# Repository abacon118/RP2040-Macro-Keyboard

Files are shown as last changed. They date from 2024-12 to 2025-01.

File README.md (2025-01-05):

# RP2040-Macro-Keyboard
This is designed to type commonly used text at the press of a button.  For example, if you type "thank you" 20 times a day, you could make that a button.  Working in IT, I can type the same server names or IP addresses multiple times in a span of a few minutes.  This allows me to type those server names at the press of one button.

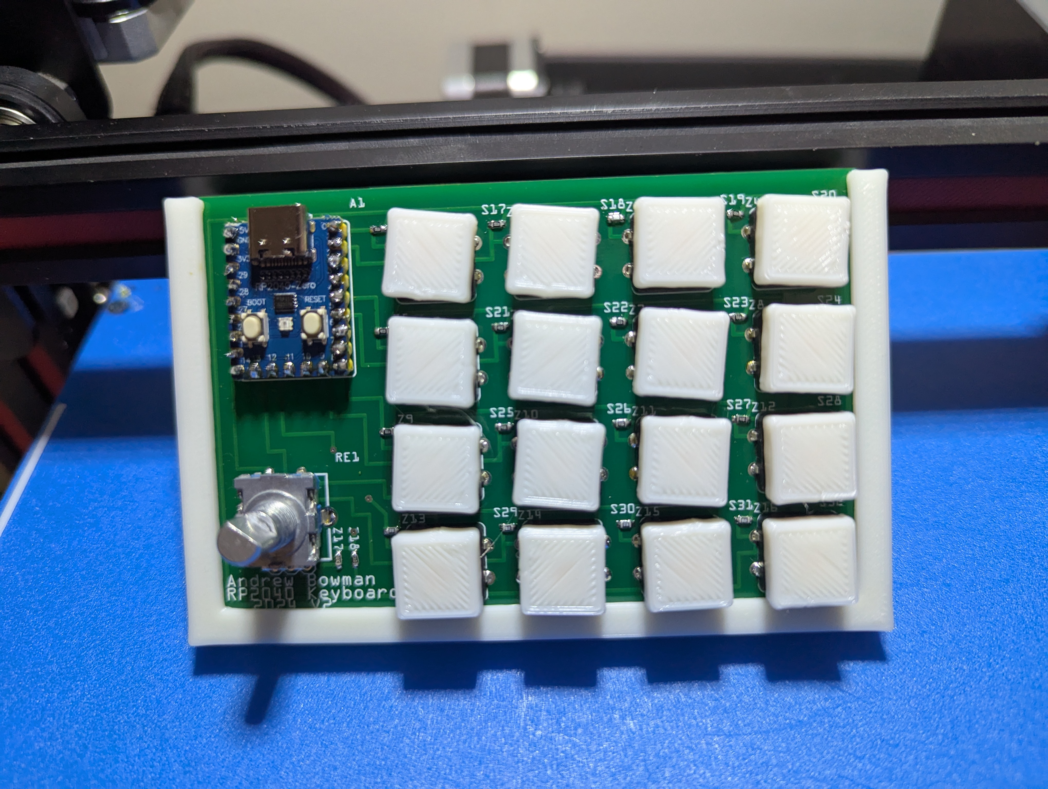
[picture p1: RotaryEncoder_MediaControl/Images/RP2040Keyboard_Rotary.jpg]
Finished PCB


## About the code
This project is written in Adafruit's Circuit python and relies on the [adafruit_hid library](https://docs.circuitpython.org/projects/hid/en/latest/api.html).  The button actions are defined in a text file called [macros.txt](ButtonsOnly/macros.txt).

## RP2040 Files/Prep
1. [Install Circuit Python on your RP2040](https://learn.adafruit.com/adafruit-feather-rp2040-pico/circuitpython)
2. Copy [lib](lib) to lib on your RP2040
3. Download and edit [macro.txt](ButtonsOnly/macros.txt).  Replace the text after the colon : with what you want each button to type.  The number coresponds to the IO number on the RP2040.
```
   00:text
```
4. Replace the contents of code.py with [PoorManMacros_1.py](ButtonsOnly/PoorManMacros_1.py)
5. If you want to disable the CIRCUITPY USB drive from showing up, add the following to boot.py.  If you need to access the CIRCUITPY drive, slow press the reset button twice.

```
   import storage
   storage.disable_usb_drive()
```

## Parts/Schematic
1x [RP2040](https://www.aliexpress.us/item/3256807710103143.html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) \
16x [1k Resistors (noted as Z1-Z16)](https://www.aliexpress.us/item/3256805478892406.html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) I used 16x 1k Ohm 0603 form factor resistors in my PCB.  If you are designing your own PCB, feel free to use something else. \
16x [12mmx12mm Buttons](https://www.aliexpress.us/item/3256805129033755.html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) \
16x [Button Caps (optional)](/STLs/12x12mm_button.stl) \
1x [PCB Bumper (optional)](/STLs/Bumper.stl) \
Rotary Encoder for Media Control (Optional)\
1x [EC11 Rotary Encoder](https://www.aliexpress.us/item/3256807457768762.html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) \
2x 10k Ohm 0603 resistors (noted as Z17, Z18) \
1x 10k Ohm through hole resistor \

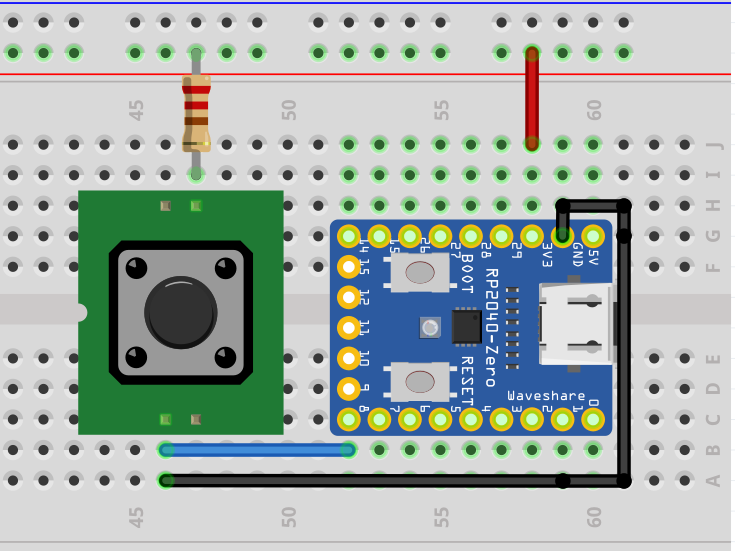
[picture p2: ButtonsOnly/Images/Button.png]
Button Setup

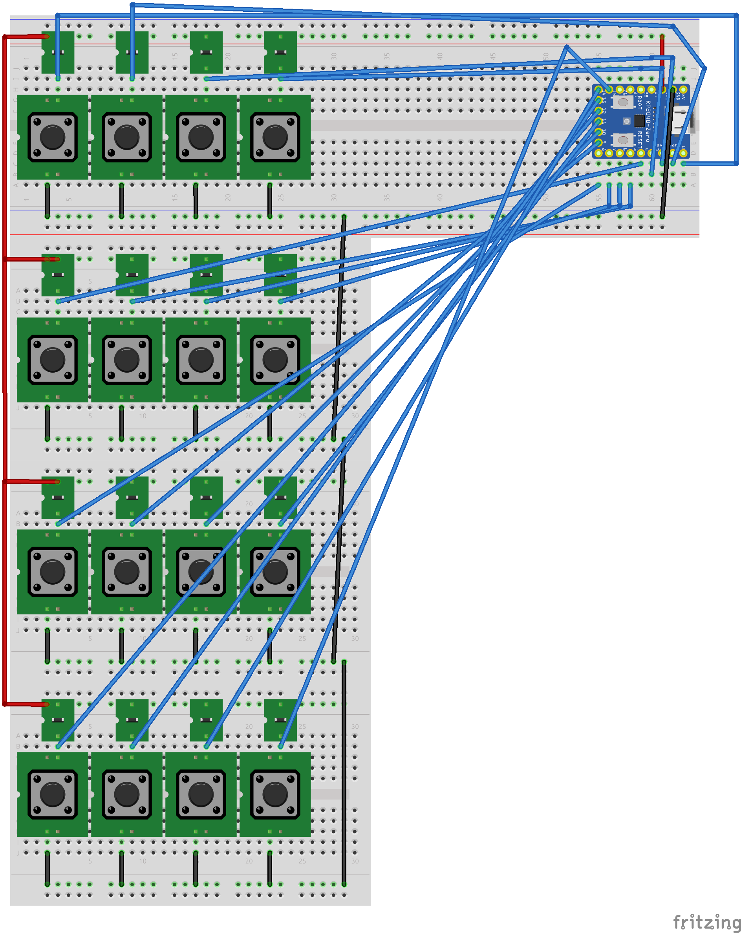
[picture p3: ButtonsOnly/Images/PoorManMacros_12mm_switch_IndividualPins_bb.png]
Schematic

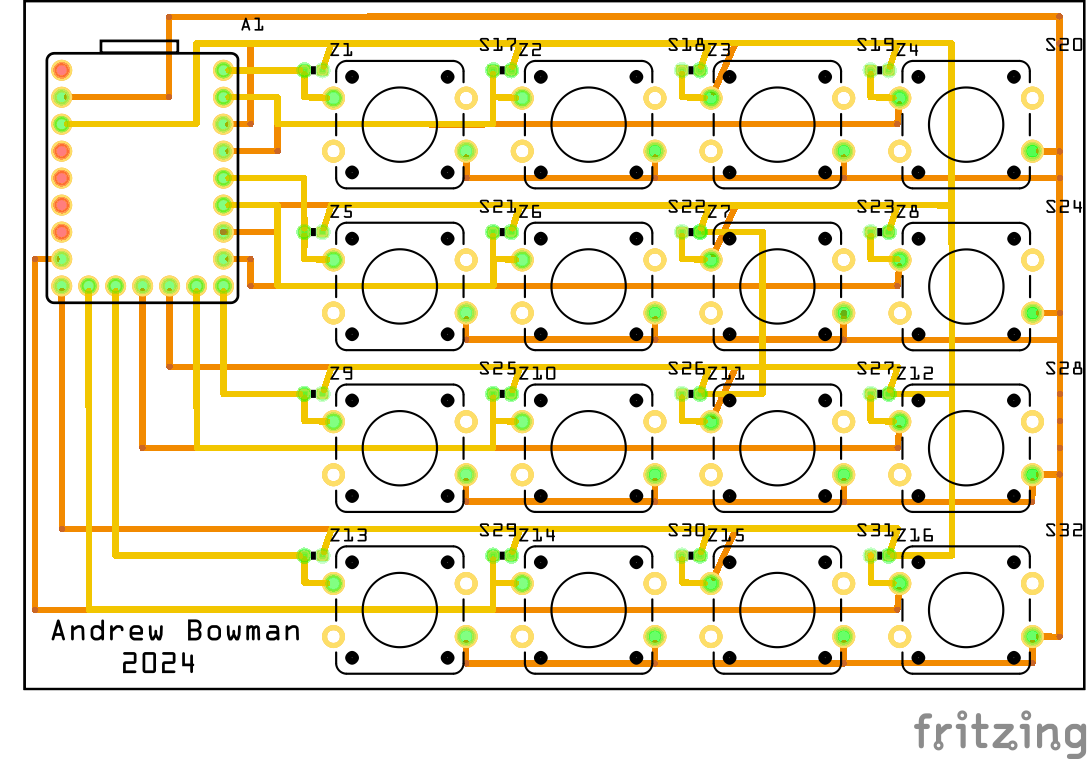
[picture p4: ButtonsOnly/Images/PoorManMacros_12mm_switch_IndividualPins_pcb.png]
PCB


## Rotary Encoder/Media Control

As a second ideration of the design, a rotary encoder was added  to allow media control (pause/play, volume up/down, next/last song).

A 10k Ohm resistor is needed between GND and Pin 26 as shown below for the button to function correctly.

The setup for the buttons is similar to how the macro buttons are defined.  These keys are using the Adafruit Consumer Control library.  Additional functions can be defined as needed.
```
press1:PLAY_PAUSE
doublepress:MUTE
right1:VOLUME_INCREMENT
left1:VOLUME_DECREMENT
pressright:SCAN_NEXT_TRACK
pressleft:SCAN_PREVIOUS_TRACK
```

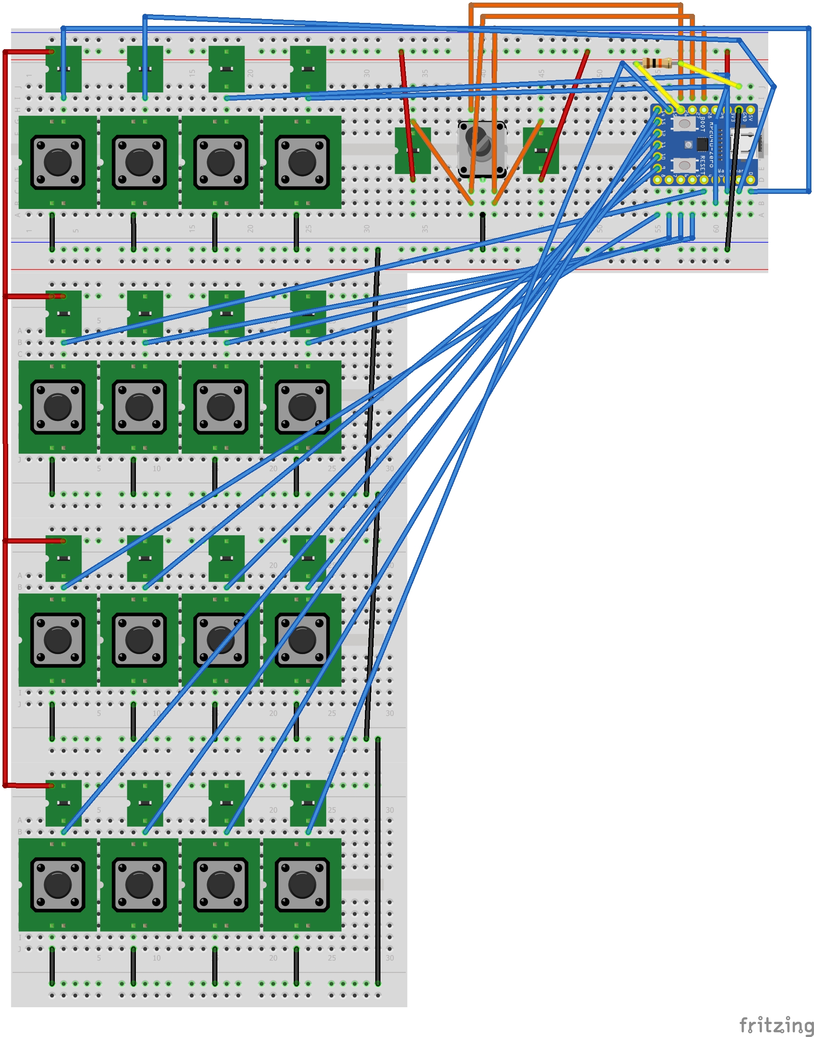
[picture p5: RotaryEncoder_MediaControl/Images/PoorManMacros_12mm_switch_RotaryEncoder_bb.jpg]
Rotary Encoder Schematic

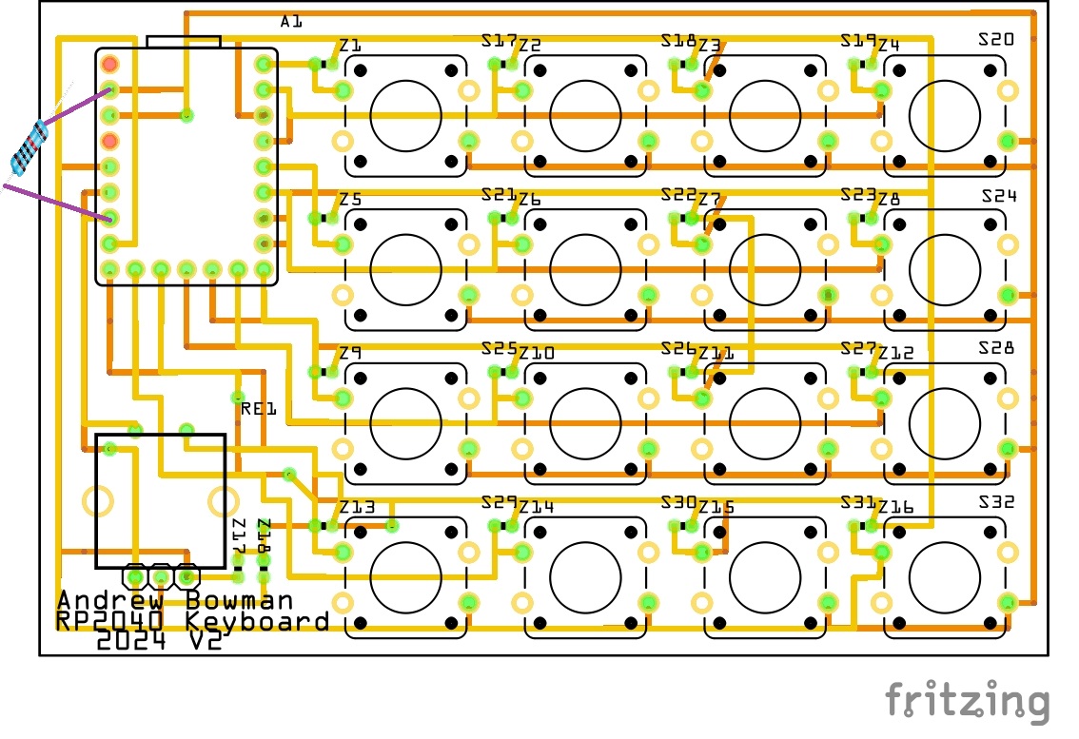
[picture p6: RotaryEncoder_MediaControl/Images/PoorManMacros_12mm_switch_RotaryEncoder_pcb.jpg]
Rotary Encoder PCB


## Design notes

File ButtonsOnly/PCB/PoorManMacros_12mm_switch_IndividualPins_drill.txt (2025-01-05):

; NON-PLATED HOLES START AT T1
; THROUGH (PLATED) HOLES START AT T100
M48
INCH
T100C0.047244
T101C0.038000
%
T100
X016414Y013984
X030414Y001984
X037414Y009952
X018492Y019984
X023414Y013984
X018492Y015952
X018492Y007984
X018492Y021952
X032500Y013979
X030414Y009952
X032492Y007984
X030414Y007984
X011492Y015952
X016414Y003952
X023414Y009952
X032492Y021952
X037414Y021952
X030414Y015952
X032492Y009952
X018492Y013984
X030414Y021952
X037414Y019984
X016414Y015952
X023414Y021952
X032492Y019984
X023414Y015952
X018492Y001984
X037421Y015947
X018492Y003952
X032500Y015947
X011492Y001984
X025492Y015952
X023414Y007984
X011492Y003952
X011492Y009952
X025492Y021952
X037414Y003952
X023414Y001984
X032492Y003952
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

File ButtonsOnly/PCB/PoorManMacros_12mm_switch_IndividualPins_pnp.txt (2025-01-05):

*Pick And Place List
*Company=
*Author=
*eMail=
*
*Project=PoorManMacros_12mm_switch_IndividualPins
*Date=18:25:06
*CreatedBy=Fritzing 0.9.10b.2022-07-01.CD-2134-0-40d23c29
*
*
*Coordinates in mm, always center of component
*Origin 0/0=Lower left corner of PCB
*Rotation in degree (0-360, math. pos.)
*
*No;Value;Package;X;Y;Rotation;Side;Name
1;;0603-res;45.0815;-58.38;0;Top;Z2
2;;0603-res;27.3015;-27.9;0;Top;Z9
3;;tactile-pth-12mm;71.0017;-38.0199;0;Bottom;S23
4;;tactile-pth-12mm;71.0017;-22.7799;0;Bottom;S27
5;;tactile-pth-12mm;71.0017;-7.53988;0;Bottom;S31
6;;tactile-pth-12mm;53.2217;-53.2599;0;Bottom;S18
7;;tactile-pth-12mm;35.4417;-38.0199;0;Bottom;S21
8;;0603-res;80.6415;-12.66;0;Top;Z16
9;;0603-res;62.8615;-27.9;0;Top;Z11
10;;tactile-pth-12mm;53.2217;-7.53988;0;Bottom;S30
11;;;12.757;-2.23344;0;Bottom;TXT1
12;;0603-res;45.0815;-43.14;0;Top;Z6
13;;0603-res;80.6415;-43.14;0;Top;Z8
14;;;14.2892;-5.30793;0;Bottom;TXT1
15;;0603-res;27.3015;-43.14;0;Top;Z5
16;;0603-res;45.0815;-12.66;0;Top;Z14
17;;0603-res;62.8615;-58.38;0;Top;Z3
18;;0603-res;62.8615;-12.66;0;Top;Z15
19;;tactile-pth-12mm;88.7817;-53.2599;0;Bottom;S20
20;;tactile-pth-12mm;35.4417;-53.2599;0;Bottom;S17
21;;tactile-pth-12mm;71.0017;-53.2599;0;Bottom;S19
22;;tactile-pth-12mm;53.2217;-22.7799;0;Bottom;S26
23;;tactile-pth-12mm;35.4417;-7.53988;0;Bottom;S29
24;;0603-res;80.6415;-58.38;0;Top;Z4
25;;tactile-pth-12mm;53.2217;-38.0199;0;Bottom;S22
26;;0603-res;27.3015;-58.38;0;Top;Z1
27;;0603-res;80.6415;-27.9;0;Top;Z12
28;;tactile-pth-12mm;88.7817;-7.53988;0;Bottom;S32
29;;0603-res;27.3015;-12.66;0;Top;Z13
30;;tactile-pth-12mm;35.4417;-22.7799;0;Bottom;S25
31;;tactile-pth-12mm;88.7817;-22.7799;0;Bottom;S28
32;;tactile-pth-12mm;88.8011;-38.0072;0;Bottom;S24
33;;0603-res;62.8615;-43.14;0;Top;Z7
34;;0603-res;45.0815;-27.9;0;Top;Z10
35;;THT;11.1959;-48.8141;0;Bottom;A1

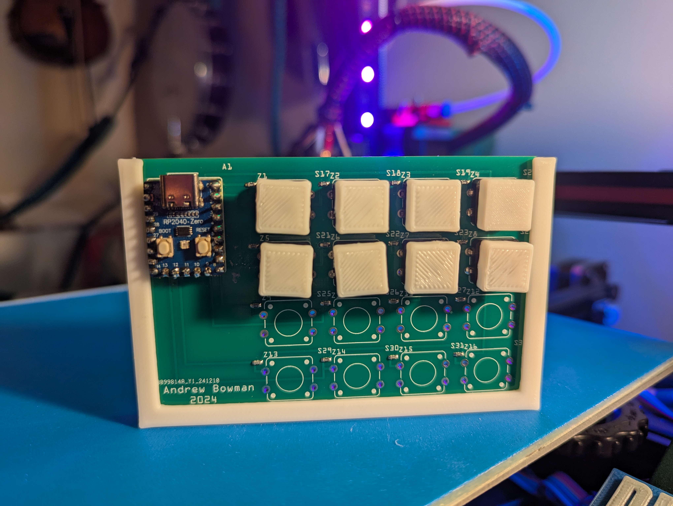
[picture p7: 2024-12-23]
Photos/ButtonOnly_Front.jpg

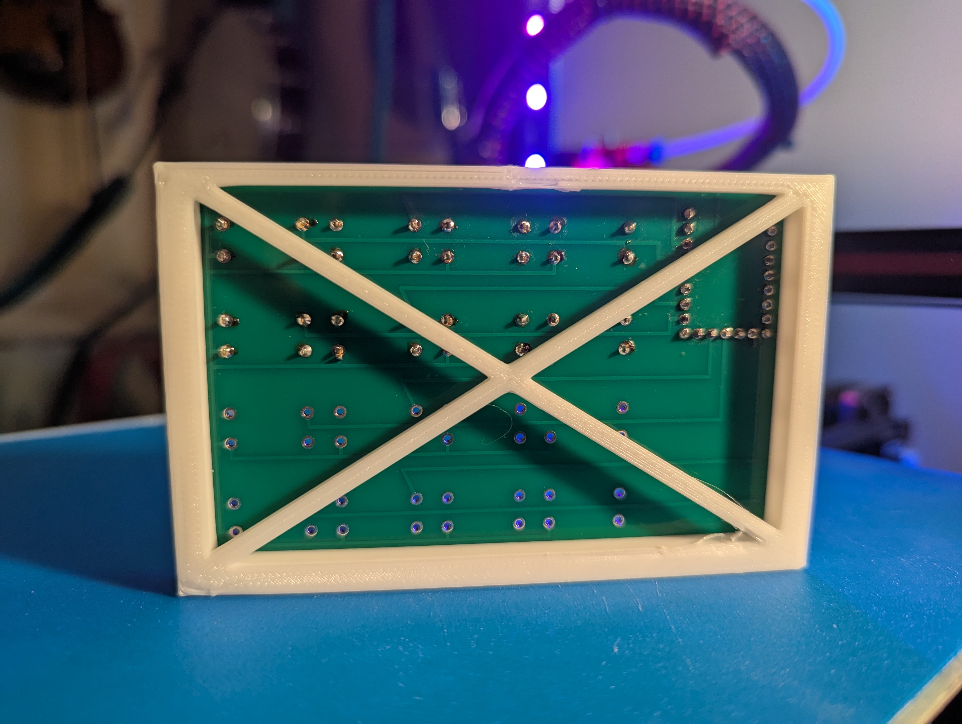
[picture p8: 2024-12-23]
Photos/ButtonOnly_Back.jpg

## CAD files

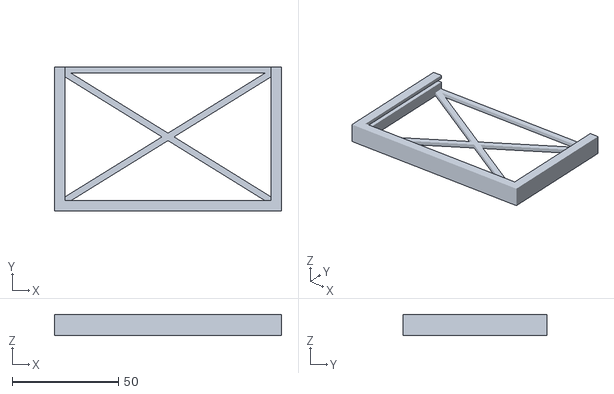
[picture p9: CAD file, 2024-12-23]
STLs/Bumper.stl
107.0 x 68.0 x 10.0

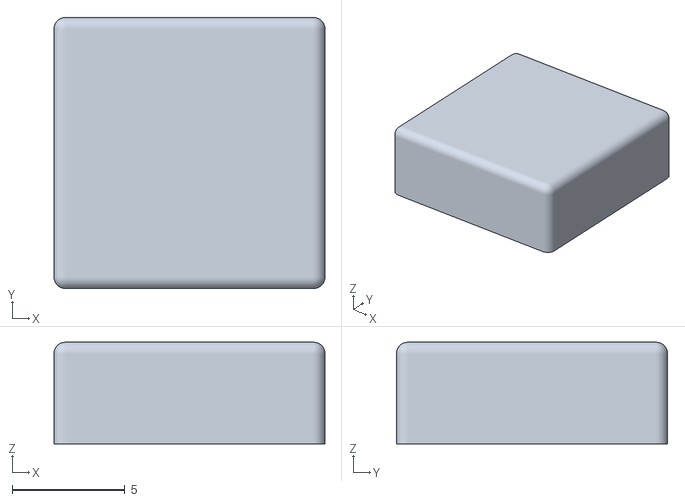
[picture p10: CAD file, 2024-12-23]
STLs/12x12mm_button.stl
12.0 x 12.0 x 4.50

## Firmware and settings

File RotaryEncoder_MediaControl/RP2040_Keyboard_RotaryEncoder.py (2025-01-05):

# Andrew Bowman 2024
# RP2040 Macro Keyboard V2

# You must have macros.txt on your CIRCUITPY drive for this to work.
# Rotary Encoder https://learn.adafruit.com/rotary-encoder/circuitpython
import time
import board
import digitalio
import simpleio
from digitalio import DigitalInOut, Direction, Pull
import time
import rotaryio
import busio
import usb_hid
from adafruit_hid.keyboard import Keyboard
from adafruit_hid.keyboard_layout_us import KeyboardLayoutUS
from adafruit_hid.keycode import Keycode
from adafruit_hid.consumer_control import ConsumerControl
from adafruit_hid.consumer_control_code import ConsumerControlCode
import array as arr

keyboard = Keyboard(usb_hid.devices)
layout = KeyboardLayoutUS(keyboard)

# Define the input pins
io0 = digitalio.DigitalInOut(board.GP0)
io1 = digitalio.DigitalInOut(board.GP1)
io2 = digitalio.DigitalInOut(board.GP2)
io3 = digitalio.DigitalInOut(board.GP3)
io4 = digitalio.DigitalInOut(board.GP4)
io5 = digitalio.DigitalInOut(board.GP5)
io6 = digitalio.DigitalInOut(board.GP6)
io7 = digitalio.DigitalInOut(board.GP7)
io8 = digitalio.DigitalInOut(board.GP8)
io9 = digitalio.DigitalInOut(board.GP9)
io10 = digitalio.DigitalInOut(board.GP10)
io11 = digitalio.DigitalInOut(board.GP11)
io12 = digitalio.DigitalInOut(board.GP12)
io13 = digitalio.DigitalInOut(board.GP13)
io14 = digitalio.DigitalInOut(board.GP14)
io15 = digitalio.DigitalInOut(board.GP15)
io26 = digitalio.DigitalInOut(board.GP26)
encoder = rotaryio.IncrementalEncoder(board.GP27, board.GP28)

io0.pull = Pull.UP # define buttons as pull ups
io1.pull = Pull.UP
io2.pull = Pull.UP
io3.pull = Pull.UP
io4.pull = Pull.UP
io5.pull = Pull.UP
io6.pull = Pull.UP
io7.pull = Pull.UP
io8.pull = Pull.UP
io9.pull = Pull.UP
io10.pull = Pull.UP
io11.pull = Pull.UP
io12.pull = Pull.UP
io13.pull = Pull.UP
io14.pull = Pull.UP
io15.pull = Pull.UP
io26.pull = Pull.UP

cc = ConsumerControl(usb_hid.devices)
enc_button_state = None
enc_last_button_state = None
press_count = 0
last_press_time = time.monotonic()
last_position = encoder.position
DEBOUNCE_TIME = 0.2 # seconds
button_state = False
double_press_time = 0.4

consumer_control_map = { #Consumer Control map for rotary encoder
    "MUTE": ConsumerControlCode.MUTE,
    "PLAY_PAUSE": ConsumerControlCode.PLAY_PAUSE,
    "VOLUME_INCREMENT": ConsumerControlCode.VOLUME_INCREMENT,
    "VOLUME_DECREMENT": ConsumerControlCode.VOLUME_DECREMENT,
    "SCAN_NEXT_TRACK": ConsumerControlCode.SCAN_NEXT_TRACK,
    "SCAN_PREVIOUS_TRACK": ConsumerControlCode.SCAN_PREVIOUS_TRACK
}

with open('macros.txt', 'r') as file: # Parse macros.txt for each line
    for line in file:
        if '00:' in line:
            text0 = line.split('00:')[1].strip()  # Sets text0 equal to the first line of the fule after 00:
        if '01:' in line:
            text1 = line.split('01:')[1].strip()
        if '02:' in line:
            text2 = line.split('02:')[1].strip()
        if '03:' in line:
            text3 = line.split('03:')[1].strip()
        if '04:' in line:
            text4 = line.split('04:')[1].strip()
        if '05:' in line:
            text5 = line.split('05:')[1].strip()
        if '06:' in line:
            text6 = line.split('06:')[1].strip()
        if '07:' in line:
            text7 = line.split('07:')[1].strip()
        if '08:' in line:
            text8 = line.split('08:')[1].strip()
        if '09:' in line:
            text9 = line.split('09:')[1].strip()
        if '10:' in line:
            text10 = line.split('10:')[1].strip()
        if '11:' in line:
            text11 = line.split('11:')[1].strip()
        if '12:' in line:
            text12 = line.split('12:')[1].strip()
        if '13:' in line:
            text13 = line.split('13:')[1].strip()
        if '14:' in line:
            text14 = line.split('14:')[1].strip()
        if '15:' in line:
            text15 = line.split('15:')[1].strip()
        if 'press1:' in line:
            press = line.split('press1:')[1].strip()
            press1 = consumer_control_map.get(press)
        if 'doublepress:' in line:
            press = line.split('doublepress:')[1].strip()
            doublepress = consumer_control_map.get(press)
        if 'right1:' in line:
            press = line.split('right1:')[1].strip()
            right = consumer_control_map.get(press) 
        if 'left1:' in line:
            press = line.split('left1:')[1].strip()
            left = consumer_control_map.get(press)
        if 'pressright:' in line:
            press = line.split('pressright:')[1].strip()
            pressright = consumer_control_map.get(press)
        if 'pressleft:' in line:
            press = line.split('pressleft:')[1].strip()
            pressleft = consumer_control_map.get(press)

while True:
    if not io0.value: # if io0.value is low, then type text0
        layout.write(text0)
    if not io1.value:
        layout.write(text1)
    if not io2.value:
        layout.write(text2)
    if not io3.value:
        layout.write(text3)
    if not io4.value:
        layout.write(text4)
    if not io5.value:
        layout.write(text5)
    if not io6.value:
        layout.write(text6)
    if not io7.value:
        layout.write(text7)
    if not io8.value:
        layout.write(text8)
    if not io9.value:
        layout.write(text9)
    if not io10.value:
        layout.write(text10)
    if not io11.value:
        layout.write(text11)
    if not io12.value:
        layout.write(text12)
    if not io13.value:
        layout.write(text13)
    if not io14.value:
        layout.write(text14)
    if not io15.value:
        layout.write(text15)
        
    current_position = encoder.position
    position_change = current_position - last_position
    enc_button_state = None
    
    if not io26.value and enc_button_state is None:
        enc_button_state = "pressed"

    
    if position_change > 0 and enc_button_state == None:
        for _ in range(position_change):
            cc.send(pressright)
        print(current_position)
    elif position_change < 0 and enc_button_state == None:
        for _ in range(-position_change):
            cc.send(pressleft)
        print(current_position)
    elif position_change > 0 and enc_button_state == "pressed":
        for _ in range(position_change):
            cc.send(left)
        print(current_position)
        time.sleep(2)
    elif position_change < 0 and enc_button_state == "pressed":
        for _ in range(-position_change):
            cc.send(right)
        print(current_position)
        time.sleep(2)

    current_time = time.monotonic()

    if not io26.value and not button_state:
        button_state = True
        if current_time - last_press_time < double_press_time :
            press_count = press_count + 1
        else:
            press_count = 1
        last_press_time = current_time
        
    if io26.value and button_state:
        button_state = False
        
    if press_count == 1 and current_time - last_press_time >= double_press_time:
        cc.send(press1)
        press_count = 0
    elif press_count == 2:
        cc.send(doublepress)
        press_count = 0
        
    last_position = current_position
          
    keyboard.release_all()
    time.sleep(0.05);

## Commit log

2024-12-15 Nessicary Circuit Python Libraries
    https://circuitpython.org/libraries
2024-12-22 PCB Gerber/Production Files
    [PoorManMacros_12mm_switch_IndividualPins_contour.gm1, PoorManMacros_12mm_switch_IndividualPins_copperBottom.gbl, PoorManMacros_12mm_switch_IndividualPins_coppe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]
2024-12-22 Update PoorManMacros_1.py
    Added pullups for buttons 2 to 15
    Added comments
2024-12-24 Update PoorManMacros_1.py
    fixed comments, cleaned up code
    [PoorManMacros_1.py]
2025-01-05 Update RP2040_Keyboard_RotaryEncoder.py
    Fixed rotary encoder to work with PCB
    Moved rotary encoder actions to text file
    [RP2040_Keyboard_RotaryEncoder.py]
2025-01-05 moving files
    [PoorManMacros_12mm_switch_IndividualPins.fzz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]
